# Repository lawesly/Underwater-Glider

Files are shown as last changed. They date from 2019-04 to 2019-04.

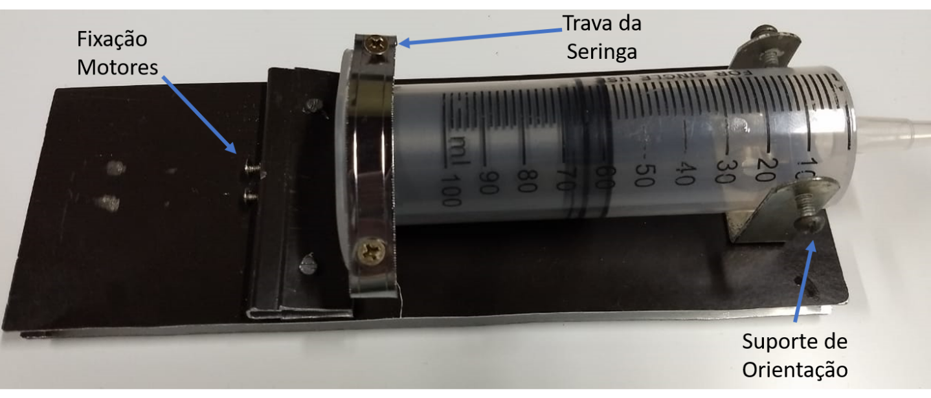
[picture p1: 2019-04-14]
Photos/mecanismo.png

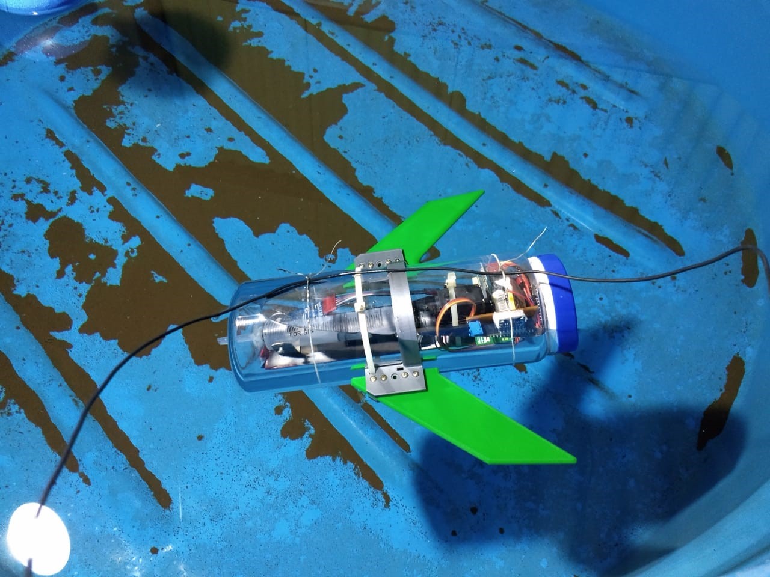
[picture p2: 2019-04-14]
Photos/glider2.jpg

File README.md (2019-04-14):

# Underwater-Glider
Projeto de concepção e construção de um glider subaquático de baixo custo

Assembly v5

# Resumo

Este projeto aborda o estudo de veículos subaquáticos de navegação autônoma, sendo seu foco principal a modelagem e construção de um protótipo do tipo Glider. Este robô pode ser definido como um veículo planador subaquático de baixo gasto energético que se locomove somente com a alteração de  seu peso e movimentação do centro de massa. Através deste trabalho foi realizando um estudo dos principais modelos existentes assim como suas principais características de funcionamento. Após este estudo foram pesquisadas técnicas para concepção do protótipo funcional junto de sua instrumentação básica. A conclusão de toda esta metodologia foi a construção de um glider, em escala simplificada, desenvolvido totalmente através do uso de técnicas e materiais de baixo custo que será compartilhado de forma gratuita com a comunidade de acadêmica. Com base nestes resultados, foi possível identificar os pontos de melhoria que serão aplicados em próximas versões, tornando o protótipo um produto confiável, de fácil reprodução e que poderá ser utilizado para estudos de controle e sensoriamento subaquático de maneira simples e acessível. 

glider2

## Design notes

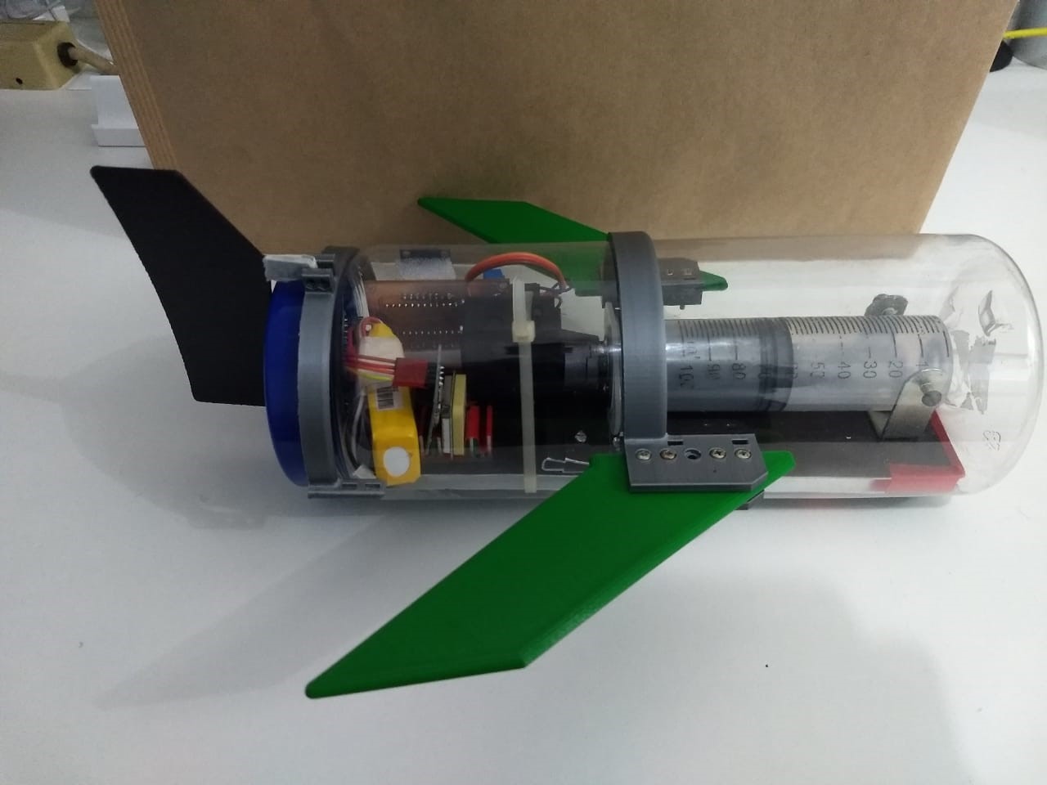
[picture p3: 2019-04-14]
Photos/glider.jpg

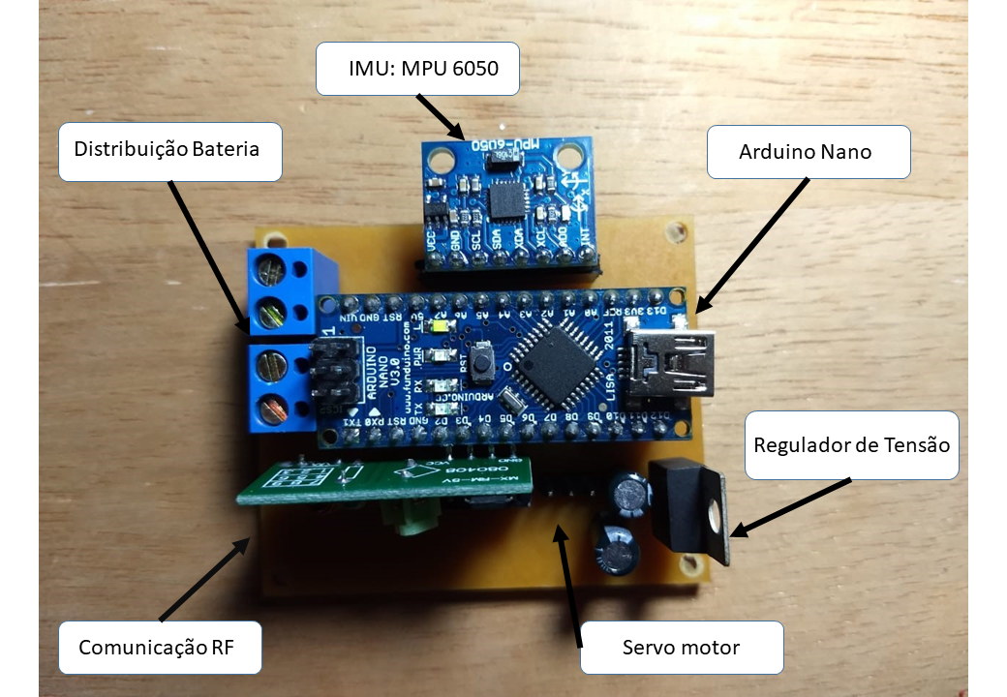
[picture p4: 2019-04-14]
Photos/Controlador.png

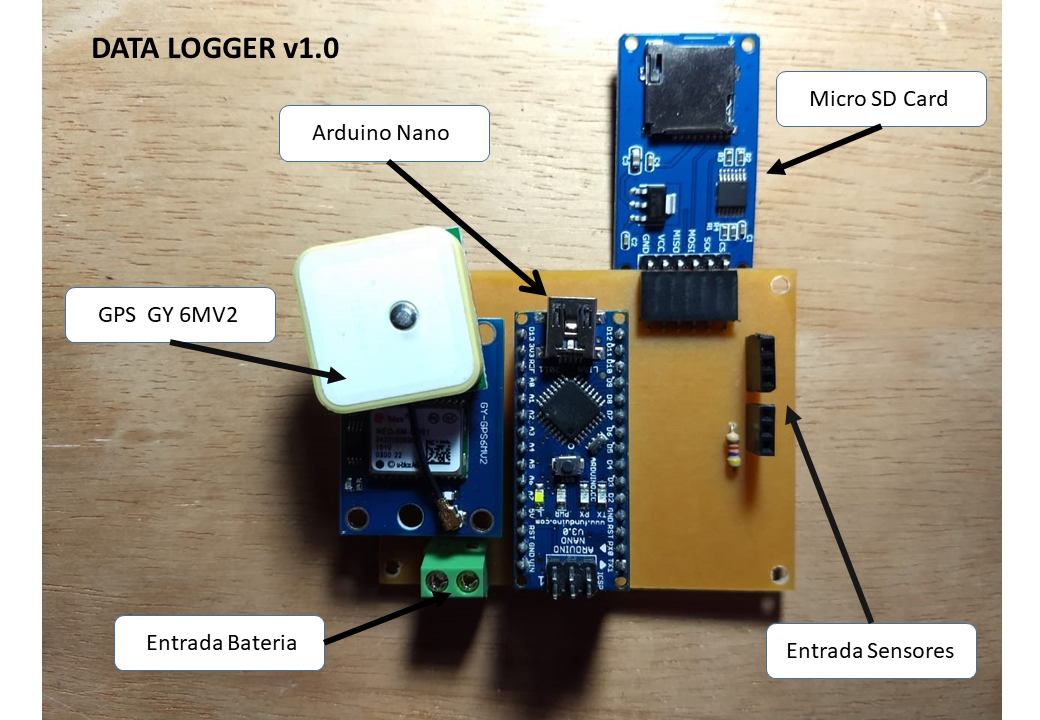
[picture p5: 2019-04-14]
Photos/DataLogger.png

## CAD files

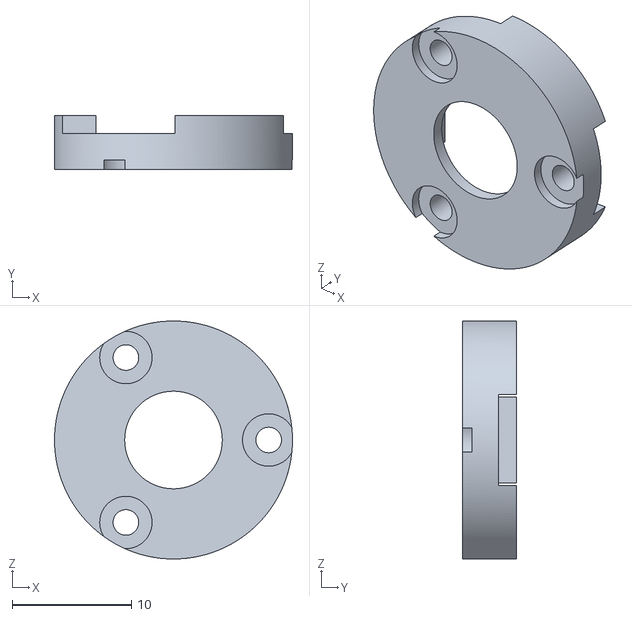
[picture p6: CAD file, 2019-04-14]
3DPrint/AcoplamentoEixo v10.stl
20.0 x 4.50 x 20.0

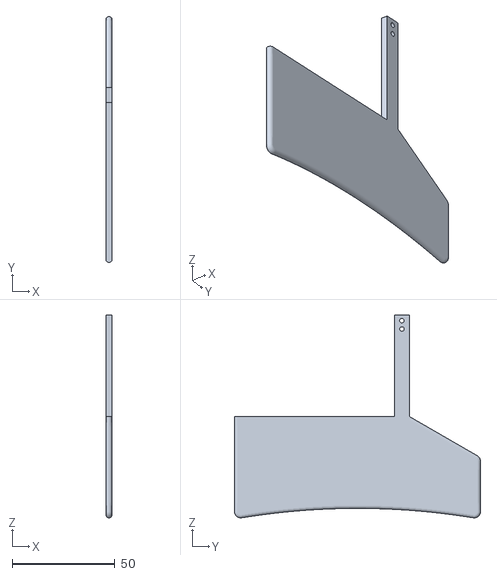
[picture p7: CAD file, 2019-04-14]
3DPrint/Rudder v9.stl
3.00 x 120.0 x 98.9

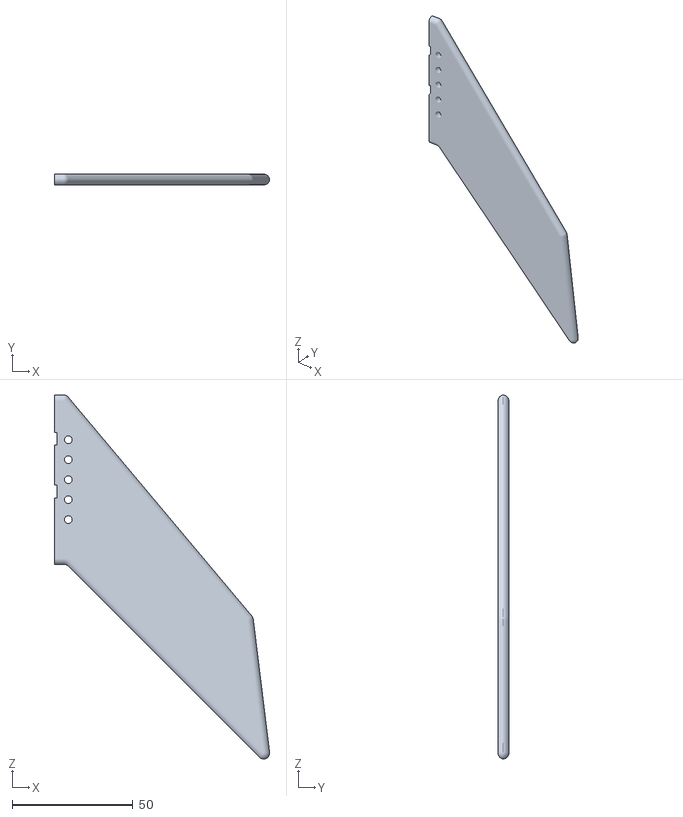
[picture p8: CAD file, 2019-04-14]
3DPrint/LargeLetfWing v6.stl
89.0 x 4.50 x 150.5

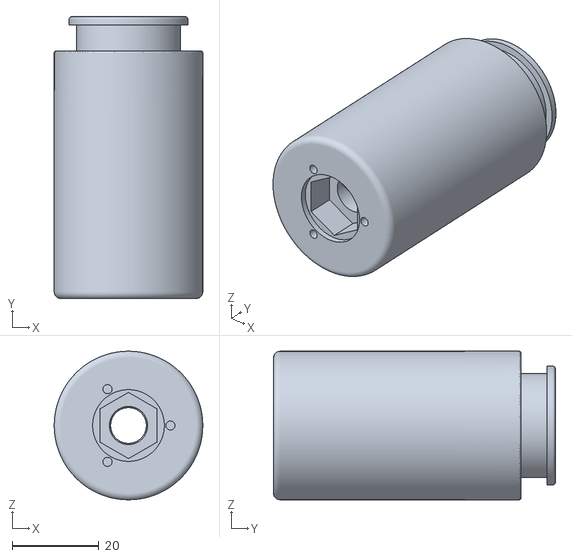
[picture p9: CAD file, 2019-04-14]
3DPrint/Balastro 100ml Syringe v13.stl
34.2 x 64.9 x 34.2

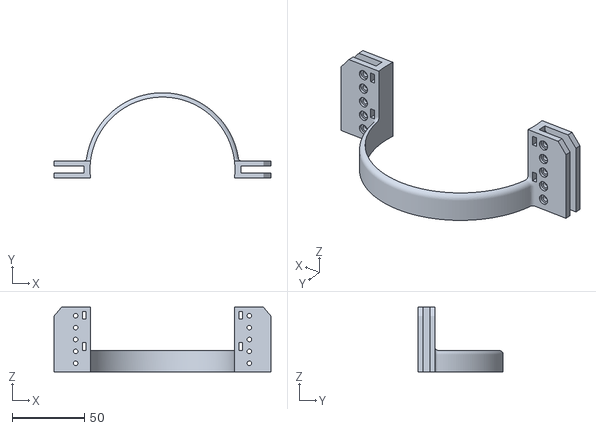
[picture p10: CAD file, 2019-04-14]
3DPrint/WingSupport v10.stl
150.4 x 59.2 x 45.0

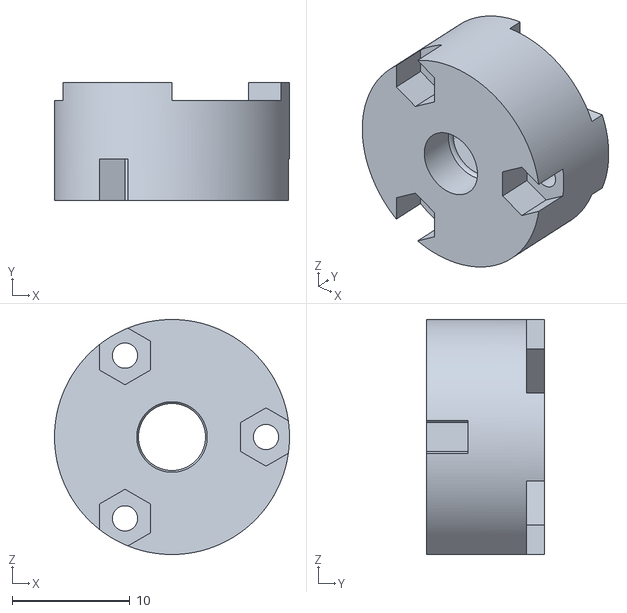
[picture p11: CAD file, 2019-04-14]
3DPrint/AcoplamentoServo v12.stl
20.0 x 10.0 x 20.0

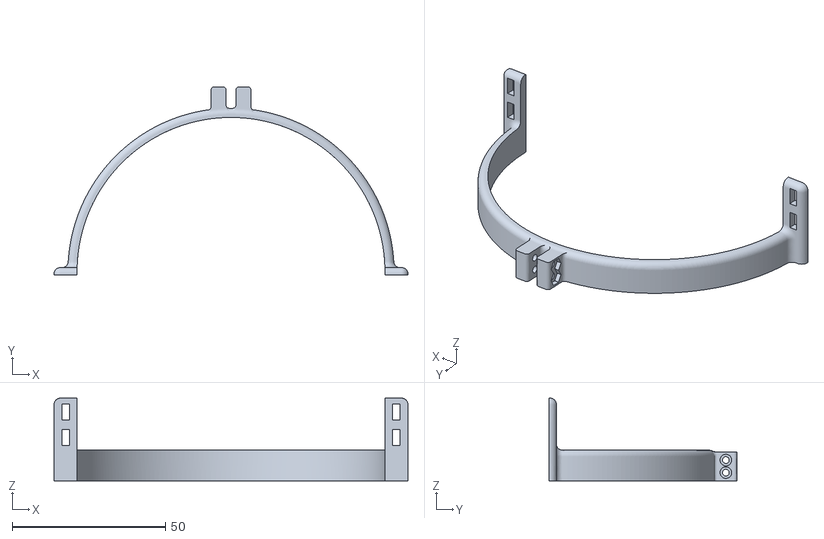
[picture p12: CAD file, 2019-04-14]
3DPrint/BackSupport v6.stl
115.5 x 61.5 x 27.0

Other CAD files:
3DPrint/LargeRigthWing v5.stl

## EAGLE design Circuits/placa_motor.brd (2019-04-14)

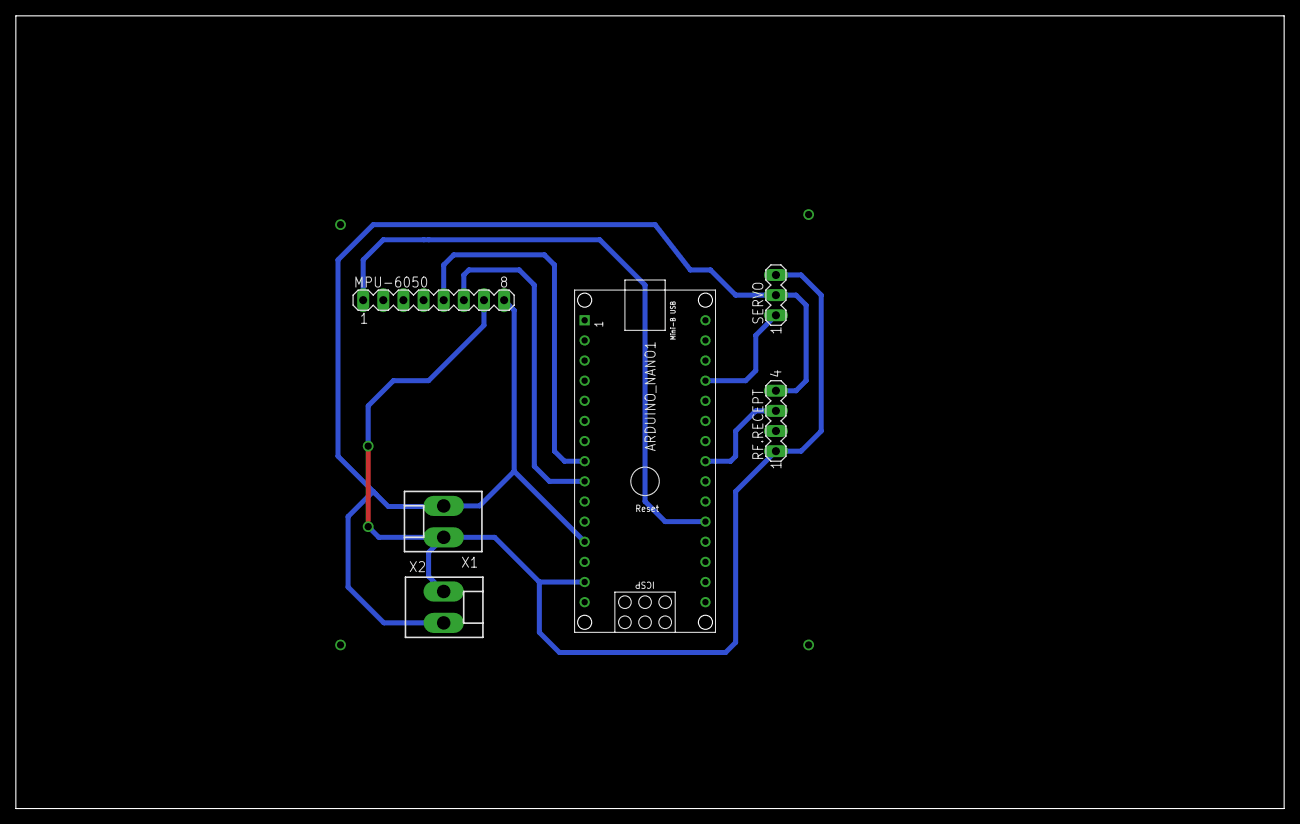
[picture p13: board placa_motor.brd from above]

Board: 2 copper layers, 160.0 x 100.0 mm, 6 parts (0 on the bottom side), 7 nets.

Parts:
ARDUINO_NANO1: ARDUINO_NANO
MPU-6050: MA08-1
RF.RECEPT: MA04-1
SERVO: MA03-1
X1, X2: KK-156-2

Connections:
5V: ARDUINO_NANO1.12, ARDUINO_NANO1.15, MPU-6050.8, RF.RECEPT.4, SERVO.2, X1.2, X2.2
GND: ARDUINO_NANO1.14, ARDUINO_NANO1.19, MPU-6050.7, RF.RECEPT.1, SERVO.3, X1.1, X2.1
INT: ARDUINO_NANO1.20, MPU-6050.1
unnamed: ARDUINO_NANO1.27, SERVO.1
unnamed: ARDUINO_NANO1.23, RF.RECEPT.3
SCL: ARDUINO_NANO1.9, MPU-6050.6
SDA: ARDUINO_NANO1.8, MPU-6050.5

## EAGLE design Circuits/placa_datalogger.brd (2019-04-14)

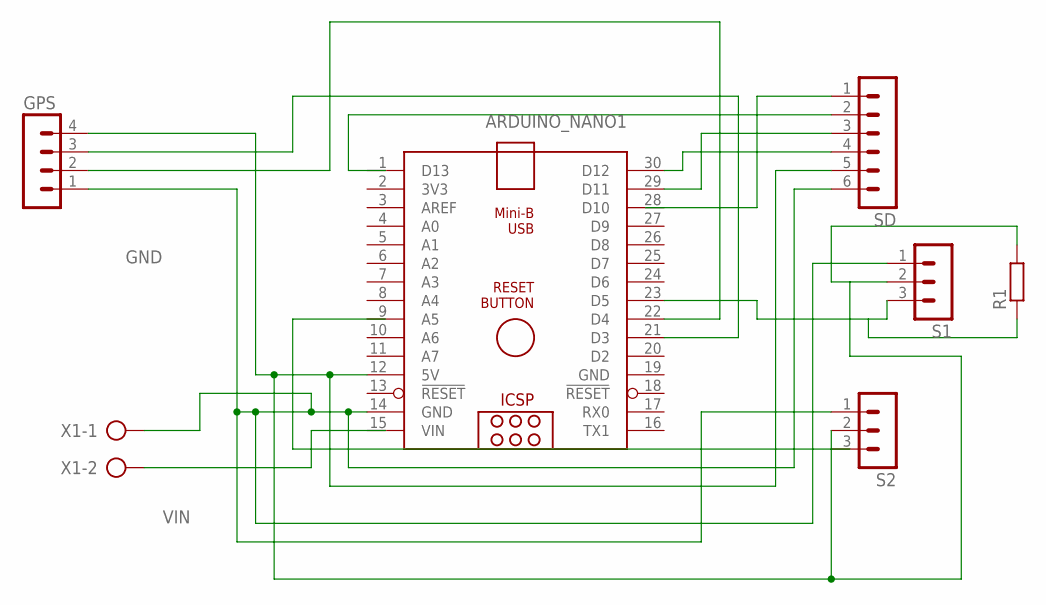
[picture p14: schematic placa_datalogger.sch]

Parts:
ARDUINO_NANO1: ARDUINO_NANO
GPS: MA04-1
R1: R-EU_0204/7; 0204/7
S1, S2: MA03-1
SD: MA06-1
X1: AK500/2-H

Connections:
5V: ARDUINO_NANO1.12 (5V), GPS.4, R1.2, S1.2, S2.2, SD.5
GND: ARDUINO_NANO1.14 (GND), ARDUINO_NANO1.19 (GND), GPS.1, S1.1, S2.1, SD.6, X1.1
unnamed: ARDUINO_NANO1.21 (D3), GPS.3
unnamed: ARDUINO_NANO1.22 (D4), GPS.2
unnamed: ARDUINO_NANO1.28 (D10), SD.1
unnamed: ARDUINO_NANO1.29 (D11), SD.3
unnamed: ARDUINO_NANO1.30 (D12), SD.4
unnamed: ARDUINO_NANO1.23 (D5), R1.1, S1.3
VIN: ARDUINO_NANO1.15 (VIN), X1.2

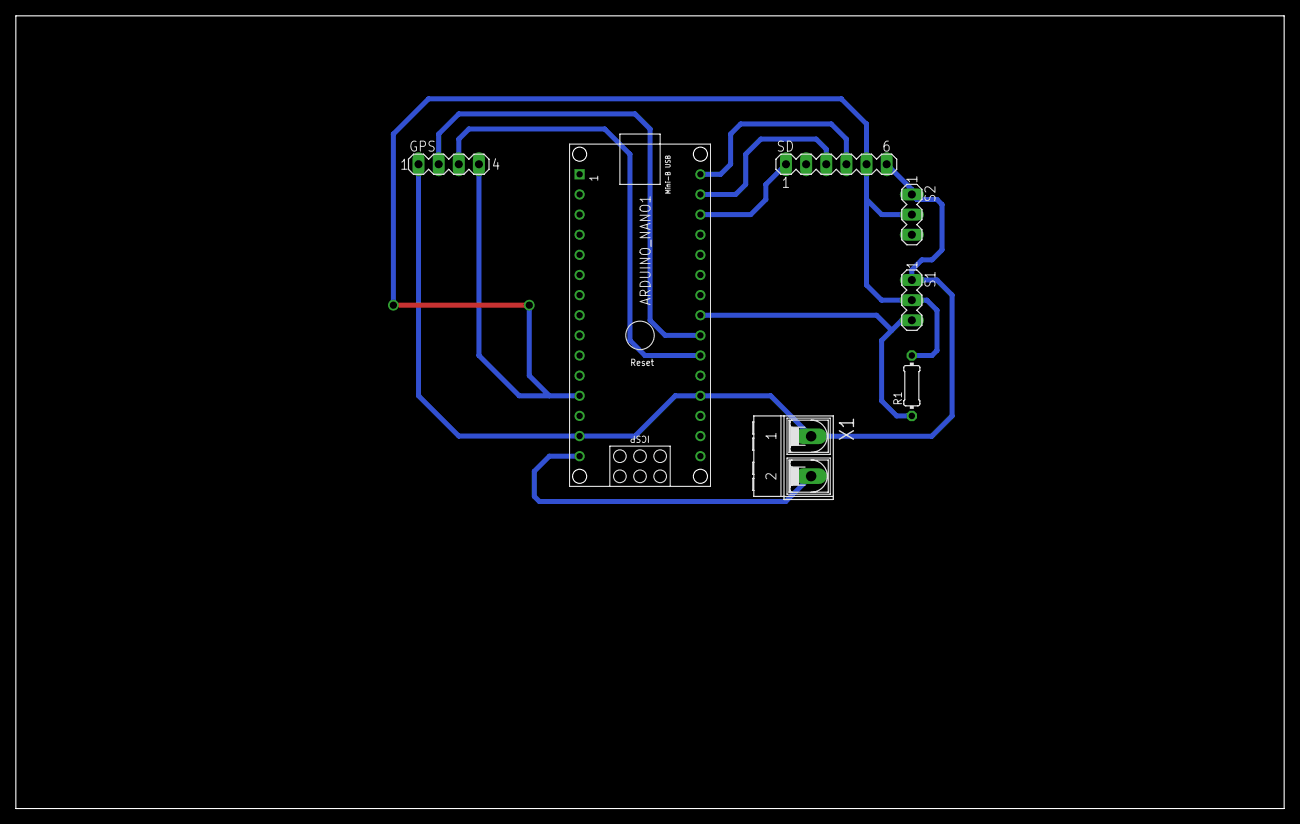
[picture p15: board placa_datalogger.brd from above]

Board: 2 copper layers, 160.0 x 100.0 mm, 7 parts (0 on the bottom side), 9 nets.

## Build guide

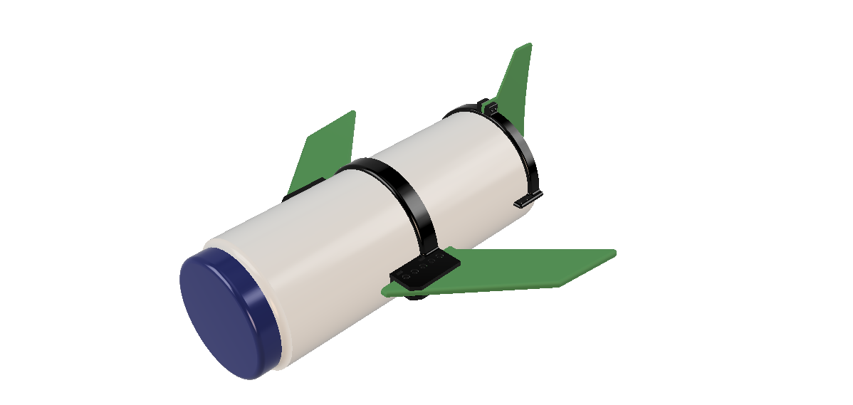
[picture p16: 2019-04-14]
Photos/Assembly v5.png

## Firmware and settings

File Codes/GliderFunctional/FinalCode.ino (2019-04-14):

#include <MPU6050_tockn.h>
#include <Wire.h>
#include <Servo.h>
#include <TinyGPS++.h>
#include <SoftwareSerial.h>
#include <SPI.h>//include library code to communicate with SPI devices
#include <SD.h>//include library code for SD card

const int chipSelect = 10;

Servo myservo;  // create servo object to control a servo

TinyGPSPlus gps;// The TinyGPS++ object

SoftwareSerial ss(4, 3);// The serial connection to the GPS device (RX=4 e TX=3)

double readAngle = 0;
int setpointD = -30; //angulo desejado de descida
double error = 0;

//Controle de tempo
unsigned long previousMillis = 0;
const long interval = 1000; //intervalo de tempo para Descida
unsigned long currentMillis = 0;

//Variaveis de Controle
double P = 0,
       I = 0,
       D = 0;

double kP = 1,
       kI = 0,
       kD = 0;
int controleMotor = 0;

MPU6050 mpu6050(Wire);

void setup() {
  Serial.begin(9600);
  Wire.begin();
  myservo.attach(9);
  mpu6050.begin();
  mpu6050.calcGyroOffsets(true);
  ss.begin(9600);
  //inicialização do SD Cards
  if (!SD.begin(chipSelect)) {
    Serial.println("Card failed, or not present!");
    return;
  }
  File dataFile = SD.open("gps.csv", FILE_WRITE); //opens file
  if (dataFile) { //if the file opened ok, writes to it
    dataFile.println("Date, Time , Lat , Long , Sats , HDOP , Alt, Speed");//prints the headings for our data
  }
  dataFile.close();//file closed
}

void loop() {

  mpu6050.update();//atualiza leitura da IMU
  //monitorSerial_Angles();//exibição dos agulos lidos através do Monitor Serial
  currentMillis = millis();
  //armzena o valor do angulo em X na variavel readAngle
  readAngle = mpu6050.getAngleX();

  if (currentMillis - previousMillis >= interval) {
    previousMillis = currentMillis;

    Serial.print("readAngle: ");
    Serial.println(readAngle);

    //converte para controle
    controleMotor = 90 + PID() ;

    if (controleMotor > 180) { //Limita velocidade maxima no sentido horário
      controleMotor = 180;
    }
    if (controleMotor < 0) { //Limita velcidade máxima no sentido anti-horário
      controleMotor = 0;
    }
    //Saída do Controle
    myservo.write(controleMotor);
  }

  while(ss.available() > 0) {
    gps.encode(ss.read());
    if (gps.location.isUpdated()) {
      Serial.println("GPS Ativado");
      monitorSerial_GPS();
      File dataFile = SD.open("gpsdata.csv", FILE_WRITE);//The routine for writing data to SD card:
      if (dataFile) {// if the file is available, write to it:
        gps.encode(ss.read());
        Serial.println("Printing In SD ");
        dataFile.print(gps.date.value());
        dataFile.print("/");
        dataFile.print(gps.time.value());
        dataFile.print("/");
        dataFile.print(gps.location.lat(), 6);
        dataFile.print("/");
        dataFile.print(gps.location.lng(), 6);
        dataFile.print("/");
        dataFile.print(gps.satellites.value());
        dataFile.print("/");
        dataFile.print(gps.hdop.value());
        dataFile.print("/");
        dataFile.print(gps.altitude.meters());
        dataFile.print("/");
        dataFile.print(gps.speed.mps());
        dataFile.print("\n");
        dataFile.close();
      }
    }
  }//Fim while GPS
}

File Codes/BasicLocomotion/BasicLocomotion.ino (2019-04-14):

#include <Servo.h>

Servo myservo;

//Controle de tempo
unsigned long previousMillis = 0;
const long interval = 51000; //intervalo de tempo para Descida
unsigned long currentMillis = 0;
int pin = 1;
int controleMotor = 0;

void setup () {
  Serial.begin(9600);
  myservo.attach(9);
}
void loop() {

  currentMillis = millis();
  //Serial.print("Millis: ");
  //Serial.println(currentMillis);
  //Serial.print("PreviousMillis: ");
  //Serial.println(previousMillis);

  if (currentMillis - previousMillis >= interval) {
    pin = pin * (-1);
    controleMotor = 90;
    myservo.write(controleMotor);
    delay(5000);
    previousMillis = millis();
  }
  if (pin > 0) {
    Serial.println("Descendo.... ");
    controleMotor = 0;
    myservo.write(controleMotor);
  } else {
    Serial.println("Subindo.... ");
    controleMotor = 180;
    myservo.write(controleMotor);
  }

}

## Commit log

2019-04-14 Adição dos arquivos iniciais
    Códigos base, circuitos fotos
    [placa_datalogger.brd, placa_datalogger.sch, placa_motor.brd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]
2019-04-14 Add dos arquivos de modelagem 3D
    Arquivos stl utilizados para a fabricação das peças
    [AcoplamentoEixo v10.stl, AcoplamentoServo v12.stl, BackSupport v6.stl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]
2019-04-14 Add do código de locomoção básico
2019-04-14 Adição de fotos
